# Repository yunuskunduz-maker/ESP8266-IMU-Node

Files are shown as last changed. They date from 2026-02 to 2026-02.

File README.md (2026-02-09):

# ESP8266 Wireless IMU Node (PCB Design) 📡

## 📋 Project Summary (Overview)

This project is a battery-powered, compact, and independent **Wireless Motion Sensor** node designed for **IoT (Internet of Things)** applications.

The board reads acceleration and gyroscope data through the onboard **MPU-6050** sensor and transmits it to a Wi-Fi network (MQTT, TCP/UDP, etc.) via the **ESP8266 (ESP-12F)** module. It features an internal **Boost Converter** circuit to allow operation from a single battery cell.

---

## 🛠️ Technical Specifications

| Feature | Detail |
| :--- | :--- |
| **Microcontroller** | ESP-12F (ESP8266 Wi-Fi SoC) |
| **Sensor** | MPU-6050 (3-Axis Accelerometer + 3-Axis Gyroscope) |
| **Power Source** | 1x AA or Li-Ion Battery Cell |
| **Power Management** | **MCP1640** Boost Converter (Generates 3.3V from 0.8V input) |
| **User Interface** | 1x Programmable Button, 2x Status LEDs |
| **Antenna** | On-board PCB antenna (Keep-out zone design applied) |
| **Design Tool** | KiCad EDA |

---

## 📸 Design Gallery

### 1. 3D Render
A 3D render of the final board assembly. The placement of the battery holder and the ESP module has been optimized for size.

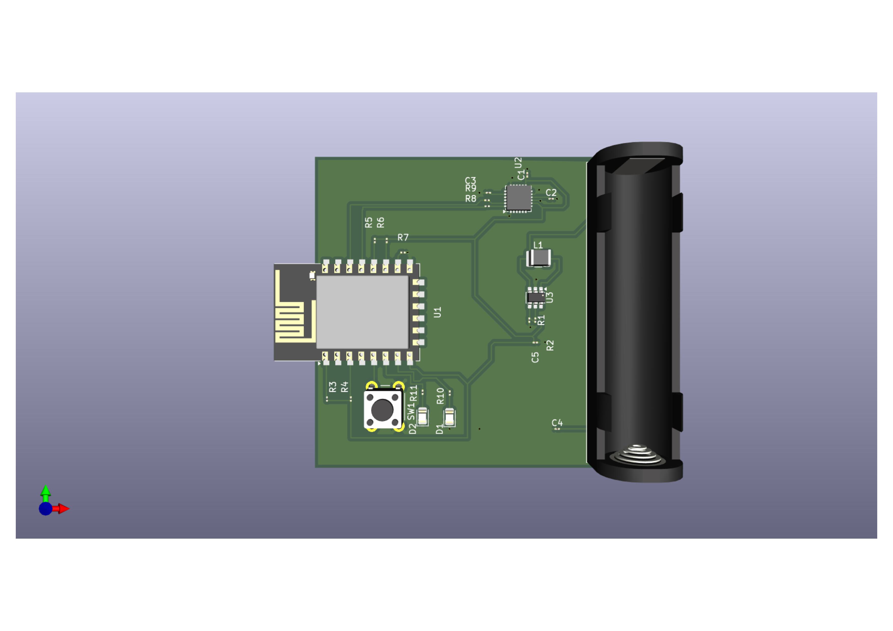
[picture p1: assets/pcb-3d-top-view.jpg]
3D View


### 2. PCB Layout & Routing
A dual-layer (2-Layer) design. "Keep-out" areas were strictly maintained in the RF (Antenna) section to ensure signal integrity. Power planes were kept wide to minimize electrical noise during transmission.

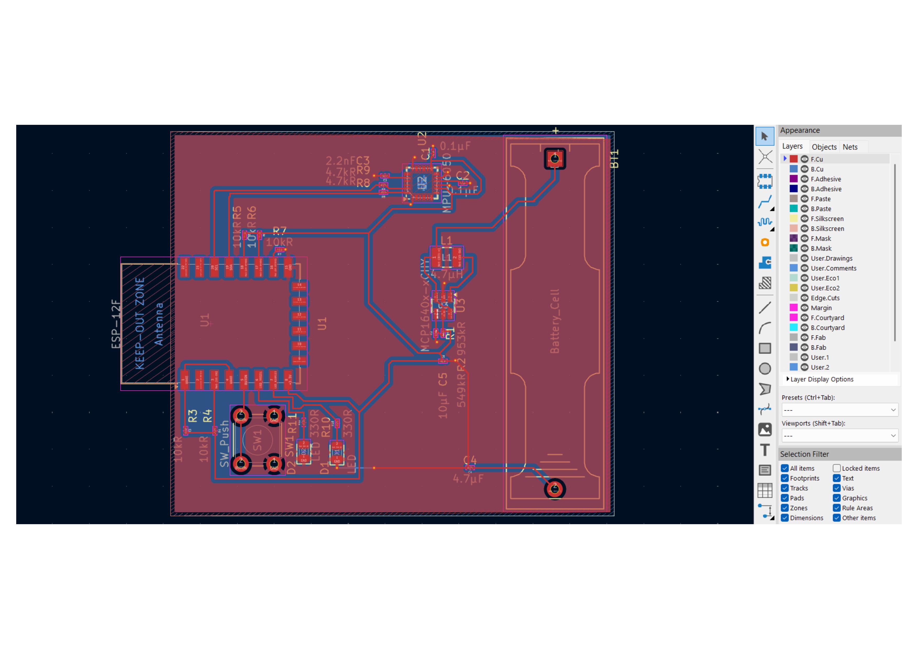
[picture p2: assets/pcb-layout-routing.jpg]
PCB Layout


### 3. Schematic Diagram
The circuit schematic illustrating the power management stage and sensor connections.

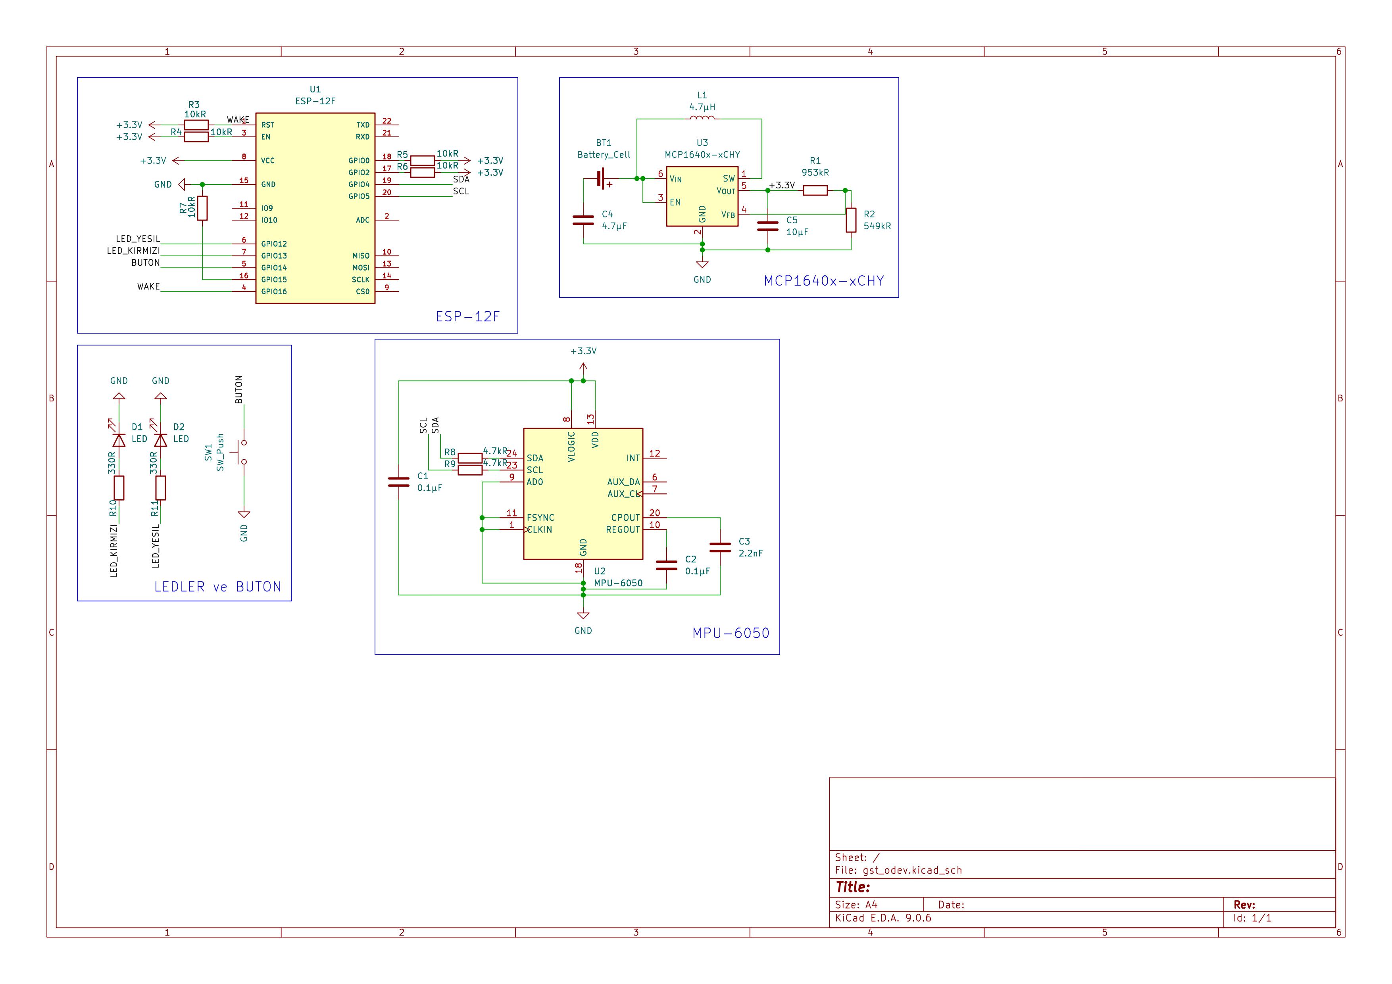
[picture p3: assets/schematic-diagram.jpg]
Schematic


---

## 🚀 Use Cases
* **Remote vibration analysis** (Machine health monitoring).
* **Wearable technologies** (Pedometer, fall detection).
* **Wireless sensor module** for robotics projects.
* **Smart home automation** triggers.

---

**License:** MIT License  
**Developer:** Yunus Kunduz

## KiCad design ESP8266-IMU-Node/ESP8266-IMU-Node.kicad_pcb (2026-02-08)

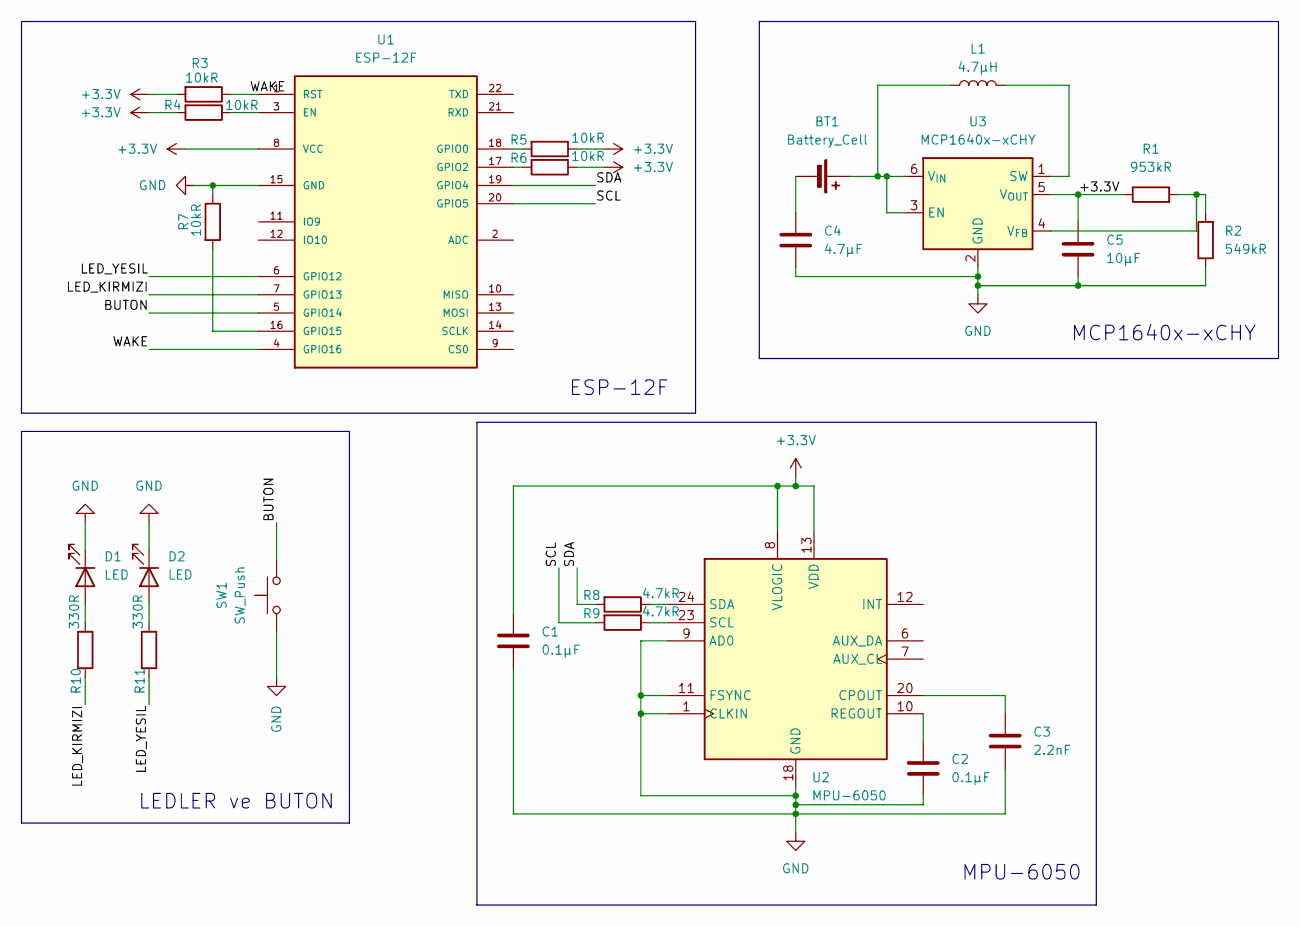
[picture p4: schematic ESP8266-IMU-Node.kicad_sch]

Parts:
BT1: Battery_Cell; BatteryHolder_Keystone_2466_1xAAA
C1, C2: 0.1μF; C_01005_0402Metric
C3: 2.2nF; C_01005_0402Metric
C4: 4.7μF; C_01005_0402Metric
C5: 10μF; C_01005_0402Metric
D1, D2: LED; LED_0805_2012Metric
L1: 4.7μH; L_1210_3225Metric
R1: 953kR; R_01005_0402Metric
R2: 549kR; R_01005_0402Metric
R3, R4, R5, R6, R7: 10kR; R_01005_0402Metric
R8, R9: 4.7kR; R_01005_0402Metric
R10, R11: 330R; R_01005_0402Metric
SW1: SW_Push; SW_PUSH_6mm
U1: ESP-12F; ESP-12E
U2: MPU-6050; InvenSense_QFN-24_4x4mm_P0.5mm
U3: MCP1640x-xCHY; SOT-23-6

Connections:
+3.3V: C1.1, C5.1, R1.1, R3.2, R4.2, R5.1, R6.1, U1.8 (VCC), U2.8 (VLOGIC), U2.13 (VDD), U3.5 (V_{OUT})
/BUTON: SW1.2, U1.5 (GPIO14)
/LED_KIRMIZI: R10.2, U1.7 (GPIO13)
/LED_YESIL: R11.2, U1.6 (GPIO12)
/SCL: R9.2, U1.20 (GPIO5)
/SDA: R8.2, U1.19 (GPIO4)
/WAKE: R3.1, U1.1 (RST), U1.4 (GPIO16)
GND: C1.2, C2.2, C3.2, C4.2, C5.2, D1.1 (K), D2.1 (K), R2.1, R7.1, SW1.1, U1.15 (GND), U2.1 (CLKIN), U2.9 (AD0), U2.11 (FSYNC), U2.18 (GND), U3.2 (GND)
unnamed: BT1.1 (+), L1.1, U3.3 (EN), U3.6 (V_{IN})
unnamed: BT1.2 (-), C4.1
unnamed: D1.2 (A), R10.1
unnamed: D2.2 (A), R11.1
unnamed: R4.1, U1.3 (EN)
unnamed: R5.2, U1.18 (GPIO0)
unnamed: R6.2, U1.17 (GPIO2)
unnamed: R7.2, U1.16 (GPIO15)
unnamed: C3.1, U2.20 (CPOUT)
unnamed: C2.1, U2.10 (REGOUT)
unnamed: R9.1, U2.23 (SCL)
unnamed: R8.1, U2.24 (SDA)
unnamed: L1.2, U3.1 (SW)
unnamed: R1.2, R2.2, U3.4 (V_{FB})

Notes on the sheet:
LEDLER ve BUTON
MPU-6050
MCP1640x-xCHY
ESP-12F

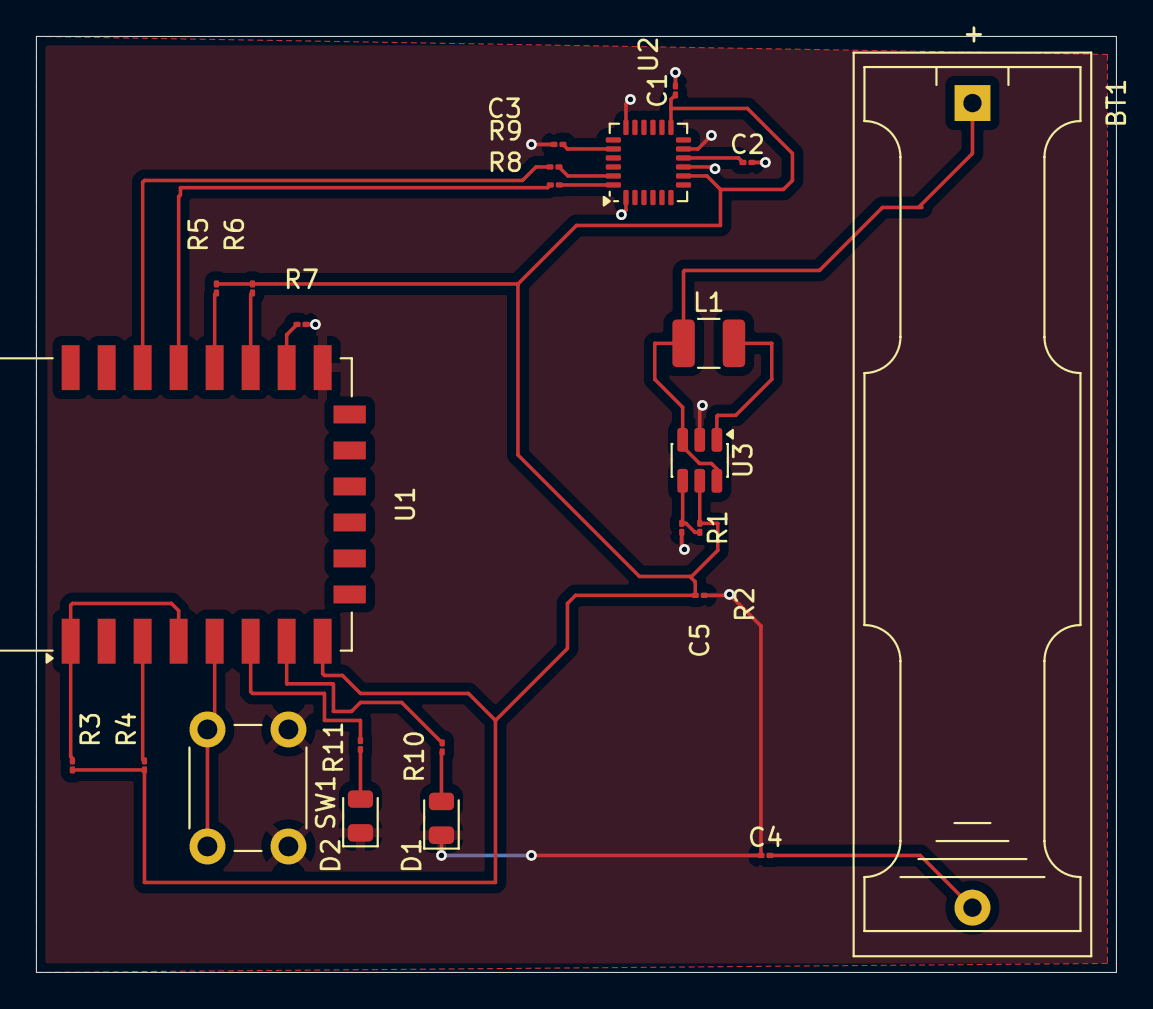
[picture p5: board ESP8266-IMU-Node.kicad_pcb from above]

Board: 2 copper layers, 60.0 x 52.0 mm, 24 parts (0 on the bottom side), 22 nets.
